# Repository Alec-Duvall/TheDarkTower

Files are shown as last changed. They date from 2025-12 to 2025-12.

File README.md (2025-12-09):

# TheDarkTower
## What is The Dark Tower?

The Dark Tower is a project inspired by Barad-dûr from The Lord of the Rings. It is a simple 3D printed base (files included) that included a mounted camera, omnidirectional servo, and laser pointer powered by a Raspberry Pi Pico. It uses some fundamental concepts related to robot vision (color segmentation, morphological opening/closing) to process a video feed sent from the RPi Pico to any computer capable of installing and running Python 3.13 and the related libraries. Currently, the tower is configured to search for greenish colors. Highly saturated greens are picked up best by the camera that was used for testing.

[A video demo is available!](https://www.youtube.com/watch?v=s9SjvUJPs3w)

## Python environment setup (Python 3.13 preferred, Python 3.14 does not work)

1) `python -m venv venv` ---> sets up environment (optional)
2) `venv\Scripts\activate` ---> enter environment for windows (optional, required with step 1)
3) `pip install -r requirements.txt` ---> install dependencies
4) `deactivate` ---> leave environment (optional, required with step 1 and 2)

## PICO environment setup

### Tutorials Referenced
- [Arducam PICO SPI Camera](https://github.com/ArduCAM/PICO_SPI_CAM)
- [OV2640 2MP Camera on Raspberry Pi Pico](https://manuals.plus/arducam/ov2640-mini-2mp-spi-camera-on-raspberry-pi-pico-manual)
1) This project uses Thonny IDE to load the RPi Pico with the firmware required to interact with color_segmentation.py. Set up the RPi Pico to use a CIRCUITPY interface when programming. If this has been done correctly, reconnect the RPi Pico and a CIRCUITPY drive should appear.
2) All code located in the PICO_DRIVERS folder should get relocated to the CIRCUITPY drive
3) Restart the RPi Pico again, boot.py should automatically establish the communication (COM) ports associated with the RPi Pico.
4) Change line 14 in color_segment.py to connect to the data COM (try both, this isn't always consistently one COM port or another!)
5) Run code.py (open code.py using Thonny IDE in the CIRCUITPY drive, click the green run button)
6) Run color_segment.py if the previous steps have all been done correctly, two camera-related windows should appear.
7) Any changes to code.py will require rerunning code.py from within the CIRCUITPY drive before changes will appear

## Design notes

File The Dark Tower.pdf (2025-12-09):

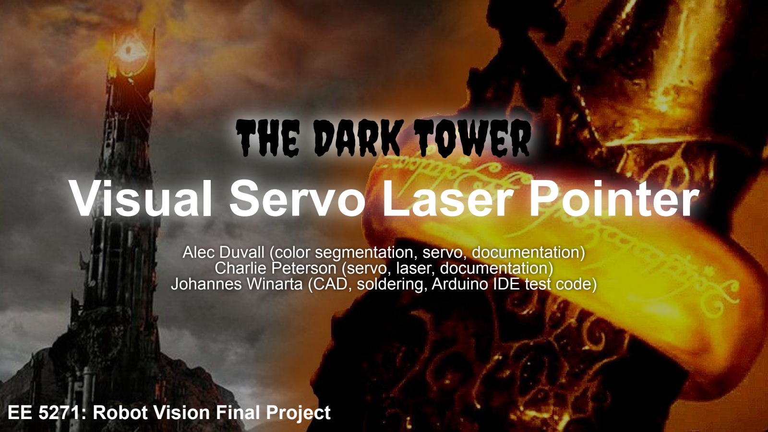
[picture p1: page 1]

# The Dark Tower

# Visual Servo Laser Pointer

Alec Duvall (color segmentation, servo, documentation) Charlie Peterson (servo, laser, documentation) Johannes Winarta (CAD, soldering, Arduino IDE test code)

EE 5271: Robot Vision Final Project

## Project Motivation/Goal

Motivation: Develop a better understanding of how robot vision techniques can be used to provide real-time feedback for control of moving systems. Demonstrate the use of color segmentation in a visual servo context.

Challenge: Tracking objects in real time with limited hardware

Goal:

- Detect a colored object using color segmentation
- Extract its centroid
- Send position data to microcontroller
- Move servo to track object in real time

## Challenges → Solutions

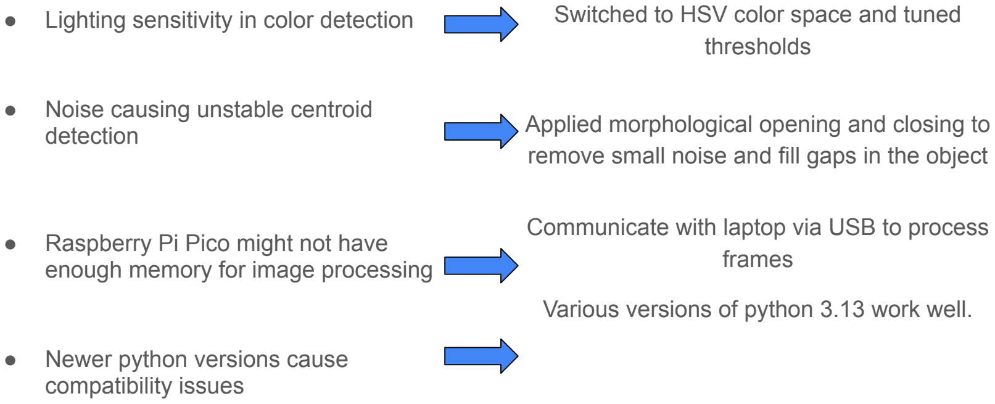
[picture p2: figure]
● Noise causing unstable centroid detection; ● Raspberry Pi Pico might not have enough memory for image processing; ● Newer python versions cause compatibility issues; Switched to HSV color space and tuned thresholds; frames

- Lighting sensitivity in color detection

Applied morphological opening and closing to remove small noise and fill gaps in the object

Communicate with laptop via USB to process

Various versions of python 3.13 work well.

## Approach/Solution

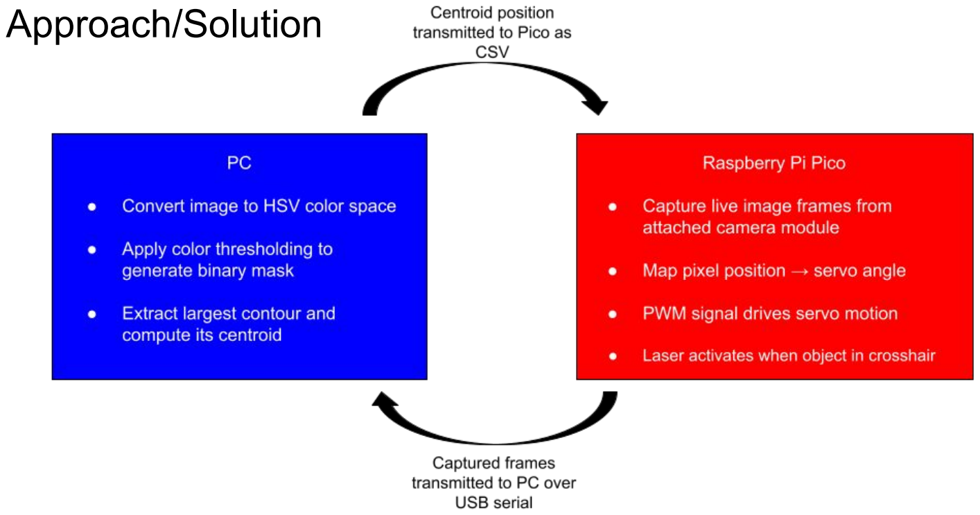
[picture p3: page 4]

## Results/Demo

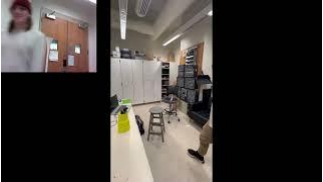
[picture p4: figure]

# QnA

### GITHUB (https://github.com/Alec-Duvall/TheDarkTower)

## Future Improvements

- Add User Interface to easily pick the color range of the object
- Implement object detection and servo positioning with more advanced methods involving a neural network or reinforcement learning
- Multiple object tracking(Servo tracks closest object or switches dynamically)
- Predictive tracking
- Object presets
- Depth estimation(stereo cameras)
- Wireless communication between the Pico and PC

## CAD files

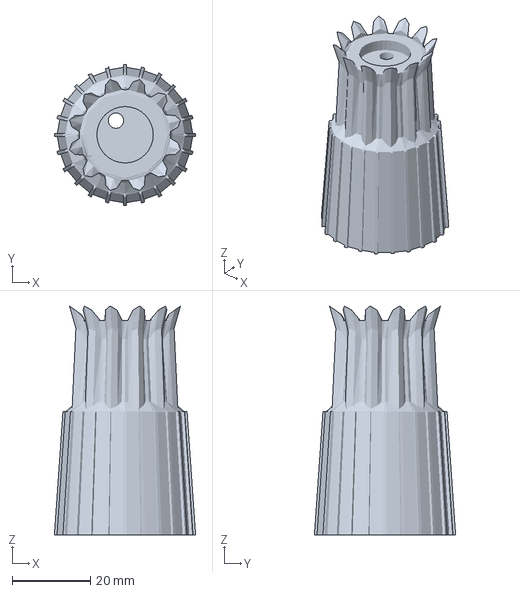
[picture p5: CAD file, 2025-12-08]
DarkTower3D_Files/DarkTowerBase.3MF
36.2 x 36.2 x 58.7 mm

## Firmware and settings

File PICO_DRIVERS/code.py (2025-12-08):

import time as utime
import board
import digitalio
import usb_cdc
import struct

from Arducam import * 

import pwmio
from adafruit_motor import servo

# Servo setup (example: GP0)
pwm_x = pwmio.PWMOut(board.GP0, frequency=50)
my_servo_x = servo.Servo(pwm_x, min_pulse=500, max_pulse=2500)

pwm_y = pwmio.PWMOut(board.GP1, frequency=50)
my_servo_y = servo.Servo(pwm_y, min_pulse=500, max_pulse=2500)




ONCE = 512          # bytes per SPI burst
RESOLUTION = 0x04   #640x480 in OV2640 example table

buf = bytearray(ONCE)

# On-board LED for status
led = digitalio.DigitalInOut(board.LED)
led.direction = digitalio.Direction.OUTPUT
led.value = False

# GP10 Laser Dot Diode
laser = digitalio.DigitalInOut(board.GP10)
laser.direction = digitalio.Direction.OUTPUT
laser.value = False

# Use the USB "data" serial port
data_serial = usb_cdc.data


def log(msg):
    # print to the console REPL
    print("[{:.3f}] {}".format(utime.monotonic(), msg))


def set_resolution(cam, value):
    if value == 0x00: cam.OV2640_set_JPEG_size(OV2640_160x120)
    elif value == 0x01: cam.OV2640_set_JPEG_size(OV2640_176x144)
    elif value == 0x02: cam.OV2640_set_JPEG_size(OV2640_320x240)
    elif value == 0x03: cam.OV2640_set_JPEG_size(OV2640_352x288)
    elif value == 0x04: cam.OV2640_set_JPEG_size(OV2640_640x480)
    elif value == 0x05: cam.OV2640_set_JPEG_size(OV2640_800x600)
    elif value == 0x06: cam.OV2640_set_JPEG_size(OV2640_1024x768)
    elif value == 0x07: cam.OV2640_set_JPEG_size(OV2640_1280x1024)
    elif value == 0x08: cam.OV2640_set_JPEG_size(OV2640_1600x1200)
    else:              cam.OV2640_set_JPEG_size(OV2640_640x480)


def send_fifo_to_usb(cam, length):
    """
    Stream one captured JPEG frame from Arducam FIFO to USB in chunks.
    Protocol: b'IMG' + 4-byte BE length + [length bytes JPEG data]
    """
    log("Streaming {} bytes over USB".format(length))
    led.value = True

    # 1) send header + length
    data_serial.write(b"IMG")
    data_serial.write(struct.pack(">I", length))

    # 2) burst-read FIFO in ONCE-byte chunks
    cam.SPI_CS_LOW()
    cam.set_fifo_burst()

    sent = 0
    try:
        while sent < length:
            n = ONCE if (length - sent) >= ONCE else (length - sent)
            # Read n bytes from SPI into buf
            cam.spi.readinto(buf, start=0, end=n)
            # Write that chunk to USB
            data_serial.write(memoryview(buf)[:n])
            sent += n
    finally:
        cam.SPI_CS_HIGH()
        cam.clear_fifo_flag()
        led.value = False

    log("Done streaming frame")


def capture_one_to_usb(cam):
    """
    Trigger a capture on the OV2640 and stream it to USB.
    """
    # Prepare FIFO
    cam.flush_fifo()
    cam.clear_fifo_flag()
    cam.start_capture()

    t0 = utime.monotonic()
    # Wait for capture done flag (with timeout)
    while cam.get_bit(ARDUCHIP_TRIG, CAP_DONE_MASK) == 0:
        if utime.monotonic() - t0 > 5.0:
            raise RuntimeError("Timeout waiting for CAP_DONE")
        utime.sleep(0.005)

    length = cam.read_fifo_length()
    if length == 0 or length > 8_000_000:
        raise RuntimeError("Bad FIFO length: {}".format(length))

    send_fifo_to_usb(cam, length)


def init_camera():
    log("Init camera")
    cam = ArducamClass(OV2640)
    cam.Camera_Init()
    set_resolution(cam, RESOLUTION)
    utime.sleep(0.3)
    log("Camera ready")
    return cam


def read_line_from_usb():
    """
    Read a line (ending with b'\\n') from the data_serial port.
    Waits until a newline shows up.
    """
    line = bytearray()
    while True:
        if data_serial.in_waiting > 0:
            b = data_serial.read(1)
            if not b:
                continue
            if b == b'\n':
                break
            line.extend(b)
        else:
            utime.sleep(0.001)
    return bytes(line)

def nx_to_angle(nx, rotation_angle_x):
    nx = max(-1.0, min(1.0, nx))
    
    rotation_angle_x += nx*10
    rotation_angle_x = max(0, min(180, rotation_angle_x))
    return rotation_angle_x

def ny_to_angle(ny, rotation_angle_y):
    ny = max(-1.0, min(1.0, ny))
    
    rotation_angle_y -= ny*10
    rotation_angle_y = max(50, min(160, rotation_angle_y))
    return rotation_angle_y

def main():
    count = 0
    shoot = 0
    cam = init_camera()
    log("Waiting for commands on USB data port...")
    rotation_angle_x = 90.0
    rotation_angle_y = 90.0
    while True:
        cmd = read_line_from_usb()
        # Frame request
        if cmd == b"CAP":
            try:
                log("CAP command received")
                capture_one_to_usb(cam)
            except Exception as e:
                log("Capture error: {}".format(e))
        else:
            log("Unknown command: {}".format(cmd))
        
        # Servo command
        try:
            parts = cmd.decode().split(',')
            if len(parts) == 2:
                count = 0
                nx = float(parts[0])
                ny = float(parts[1]) #here just in case
                rotation_angle_x = nx_to_angle(nx, rotation_angle_x)
                rotation_angle_y = ny_to_angle(ny, rotation_angle_y)
                my_servo_x.angle = rotation_angle_x
                my_servo_y.angle = rotation_angle_y
                log(f"servo_x angle: {rotation_angle_x:.1f}")
                log(f"servo_y angle: {rotation_angle_y:.1f}")
                log(f"{nx}")
                log(f"{ny}")
                if(nx < 0.05 and ny < 0.05):
                    shoot += 1
                else:
                    laser.value = False
                    shoot = 0
                if(shoot >= 3):
                    laser.value = True
            else:
                log("No green detected.")
                laser.value = False
                count += 1
                if (count >= 20): # reinitialize servo position if no objects found every 20 frames
                    rotation_angle_x = 90
                    rotation_angle_y = 90
                    my_servo_x.angle = rotation_angle_x
                    my_servo_y.angle = rotation_angle_y
                    log(f"servo_x angle: {rotation_angle_x:.1f}")
                    log(f"servo_y angle: {rotation_angle_y:.1f}")
                    count = 0

        except Exception as e:
            log(f"servo parse error: {e}")

if __name__ == "__main__":
    main()

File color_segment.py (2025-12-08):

import cv2
import numpy as np
import serial
import time
import struct

# camera config
CAM_INDEX = 0
FRAME_W, FRAME_H = 640, 480
AREA_MIN = 500  # ignore tiny blobs

# USB communication config check readme for instr of how to choose COMx value
# Also 115200 is the baud rate for UART but probably shouldnt matter since camera is SPI
ser = serial.Serial('COM6', 115200, timeout=2) #change COM3 to whatever pico shows up as in device manager
time.sleep(2) # give the pico time to reset

# HSV range use online picker to match object color as close as possible
LOWER = np.array([40, 90, 70])    # green-ish low
UPPER = np.array([85, 255, 255])  # green-ish high

# uncomment for webcam interface
# cap = cv2.VideoCapture(CAM_INDEX)
# cap.set(cv2.CAP_PROP_FRAME_WIDTH, FRAME_W)
# cap.set(cv2.CAP_PROP_FRAME_HEIGHT, FRAME_H)

# if not cap.isOpened():
#     print("Camera not found")
#     raise SystemExit

def find_largest_contour(mask, area_min=AREA_MIN):
    cnts, _ = cv2.findContours(mask, cv2.RETR_EXTERNAL, cv2.CHAIN_APPROX_SIMPLE)
    if not cnts:
        return None
    c = max(cnts, key=cv2.contourArea)
    if cv2.contourArea(c) < area_min:
        return None
    return c

def contour_centroid(contour):
    M = cv2.moments(contour)
    if M["m00"] == 0:
        return None
    cx = int(M["m10"] / M["m00"])
    cy = int(M["m01"] / M["m00"])
    return (cx, cy)

def read_exact(n):
    buf = b''
    while len(buf) < n:
        chunk = ser.read(n - len(buf))
        if not chunk:
            raise RuntimeError("Serial read timeout")
        buf += chunk
    return buf

# on pico this means wait for the command CAP
# capture an image from camera
# return frame
def get_frame_from_pico():
    # request capture
    ser.write(b"CAP\n")
    ser.flush()

    # read header 
    header = read_exact(3)
    if header != b"IMG":
        raise RuntimeError(f"Bad header from Pico: {header}")

    # read 4-byte length
    length_bytes = read_exact(4)
    (length,) = struct.unpack('>I', length_bytes)

    # read image payload
    img_bytes = read_exact(length)

    # decode image to BGR OpenCV frame
    np_arr = np.frombuffer(img_bytes, np.uint8)
    frame = cv2.imdecode(np_arr, cv2.IMREAD_COLOR)
    if frame is None:
        raise RuntimeError("Failed to decode image from Pico")

    return frame


while True:
    # uncomment to use computer webcam
    # ok, frame = cap.read()
    # if not ok:
    #     break

    frame = get_frame_from_pico()


    hsv = cv2.cvtColor(frame, cv2.COLOR_BGR2HSV)

    
    mask = cv2.inRange(hsv, LOWER, UPPER)

    # Clean up noise a bit
    # This method uses opening and closing method talked about in class
    mask = cv2.morphologyEx(mask, cv2.MORPH_OPEN, np.ones((5,5), np.uint8))
    mask = cv2.morphologyEx(mask, cv2.MORPH_CLOSE, np.ones((5,5), np.uint8))

    c = find_largest_contour(mask)
    target_found = False
    nx = ny = None  # normalized coords

    if c is not None:
        target_found = True
        # centroid
        cen = contour_centroid(c)
        if cen is not None:
            cx, cy = cen

            # draw visuals
            x,y,w,h = cv2.boundingRect(c)
            cv2.rectangle(frame, (x,y), (x+w, y+h), (0,255,0), 2)
            cv2.circle(frame, (cx, cy), 6, (0,0,255), -1)

            # normalized coords in [-1,+1], 0 = image center
            # should be easier to map to servo angles this way maybe?
            nx = (cx - FRAME_W/2) / (FRAME_W/2)
            ny = (cy - FRAME_H/2) / (FRAME_H/2)

            # create packet and send to pico, packet is CSV style,
            # could make json or some other structure if that helps
            # inverted nx and ny because camera mirrored
            packet = f"{-nx},{-ny}\n"
            ser.write(packet.encode('utf-8'))

            # crosshair at image center + text
            cv2.drawMarker(frame, (FRAME_W//2, FRAME_H//2), (255,255,255),
                           markerType=cv2.MARKER_CROSS, markerSize=20, thickness=2)
            cv2.putText(frame, f"cx={cx} cy={cy}  nx={nx:.2f} ny={ny:.2f}",
                        (10, 30), cv2.FONT_HERSHEY_SIMPLEX, 0.7, (255,255,255), 2)

    # show windows
    cv2.imshow("frame", frame)
    cv2.imshow("mask", mask)

    # print numeric values to terminal (useful for debugging/serial later)
    if target_found:
        print(f"{nx:.3f},{ny:.3f}")
    else:
        print("none")

    if cv2.waitKey(1) & 0xFF == ord('q'):
        break

# cap.release()
ser.close()
cv2.destroyAllWindows()

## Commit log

2025-12-01 Implemented ArduCam PICO communication with PC side code
2025-12-02 inverted coords sent to pico
    [color_segment.py]
2025-12-02 Added functionality for servo
2025-12-08 Add files via upload
    3D model of the Base
    [DarkTowerBase.3MF, DarkTowerBase.SLDPRT]
2025-12-08 New codebase, supports omnidirectional servo
    XY servo code, laser integrated, logic for resetting camera position and flashing the laser upon sustained object recognition
    [code.py, color_segment.py]
